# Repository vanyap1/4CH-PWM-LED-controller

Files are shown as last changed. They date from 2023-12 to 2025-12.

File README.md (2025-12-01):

# Потужний 4-канальний контролер освітлення

Контролер призначений для керування чотирма незалежними каналами освітлення за допомогою ШІМ. Підходить для амбіентного підсвічування та роботи з різними сенсорами присутності й освітленості.


## Основні можливості
- Керування **4 незалежними каналами**
- Регулювання яскравості через **ШІМ**
- Інтеграція з зовнішніми сенсорами:
  - Доплерівські сенсори присутності
  - PIR сенсори руху
  - Датчики освітленості
  - Інші сумісні датчики

## Система захисту
- **Температурний контроль** силових транзисторів
- Підтримка **зовнішнього NTC** біля навантаження
- **Захист по струму**
- **Контроль вхідної напруги** з блокуванням роботи в небезпечних діапазонах

## Технічні характеристики
- **Напруга живлення:** 12–26 В  
- **Споживання контролера:** ≤ 50 mA  
- **Максимальний струм комутації:**
  - до **12 А на канал**, або
  - до **12 А сумарно**

## Індикація роботи

### Зелений індикатор
- **Світиться** — нормальна робота  
- **Блимає** — перехідні процеси (зміна режиму, встановлення нового ШІМ)  
- **Вимкнений** — нештатна ситуація

### Червоний індикатор
- **Блимає** — відновлювані критичні стани  
  (критична напруга, перегрів, обмеження по струму, таймер блокування).  
  Виходи **вимкнені**  
- **Світиться** — фатальна помилка  
  (критичний перегрів, неможливість контролювати/відключити навантаження).  
  Скидання після перезапуску, якщо проблема не повторюється

## Програмування сценаріїв
Поведінку контролера, сценарії роботи та інтеграцію з сенсорами можна налаштовувати індивідуально під проєкт.

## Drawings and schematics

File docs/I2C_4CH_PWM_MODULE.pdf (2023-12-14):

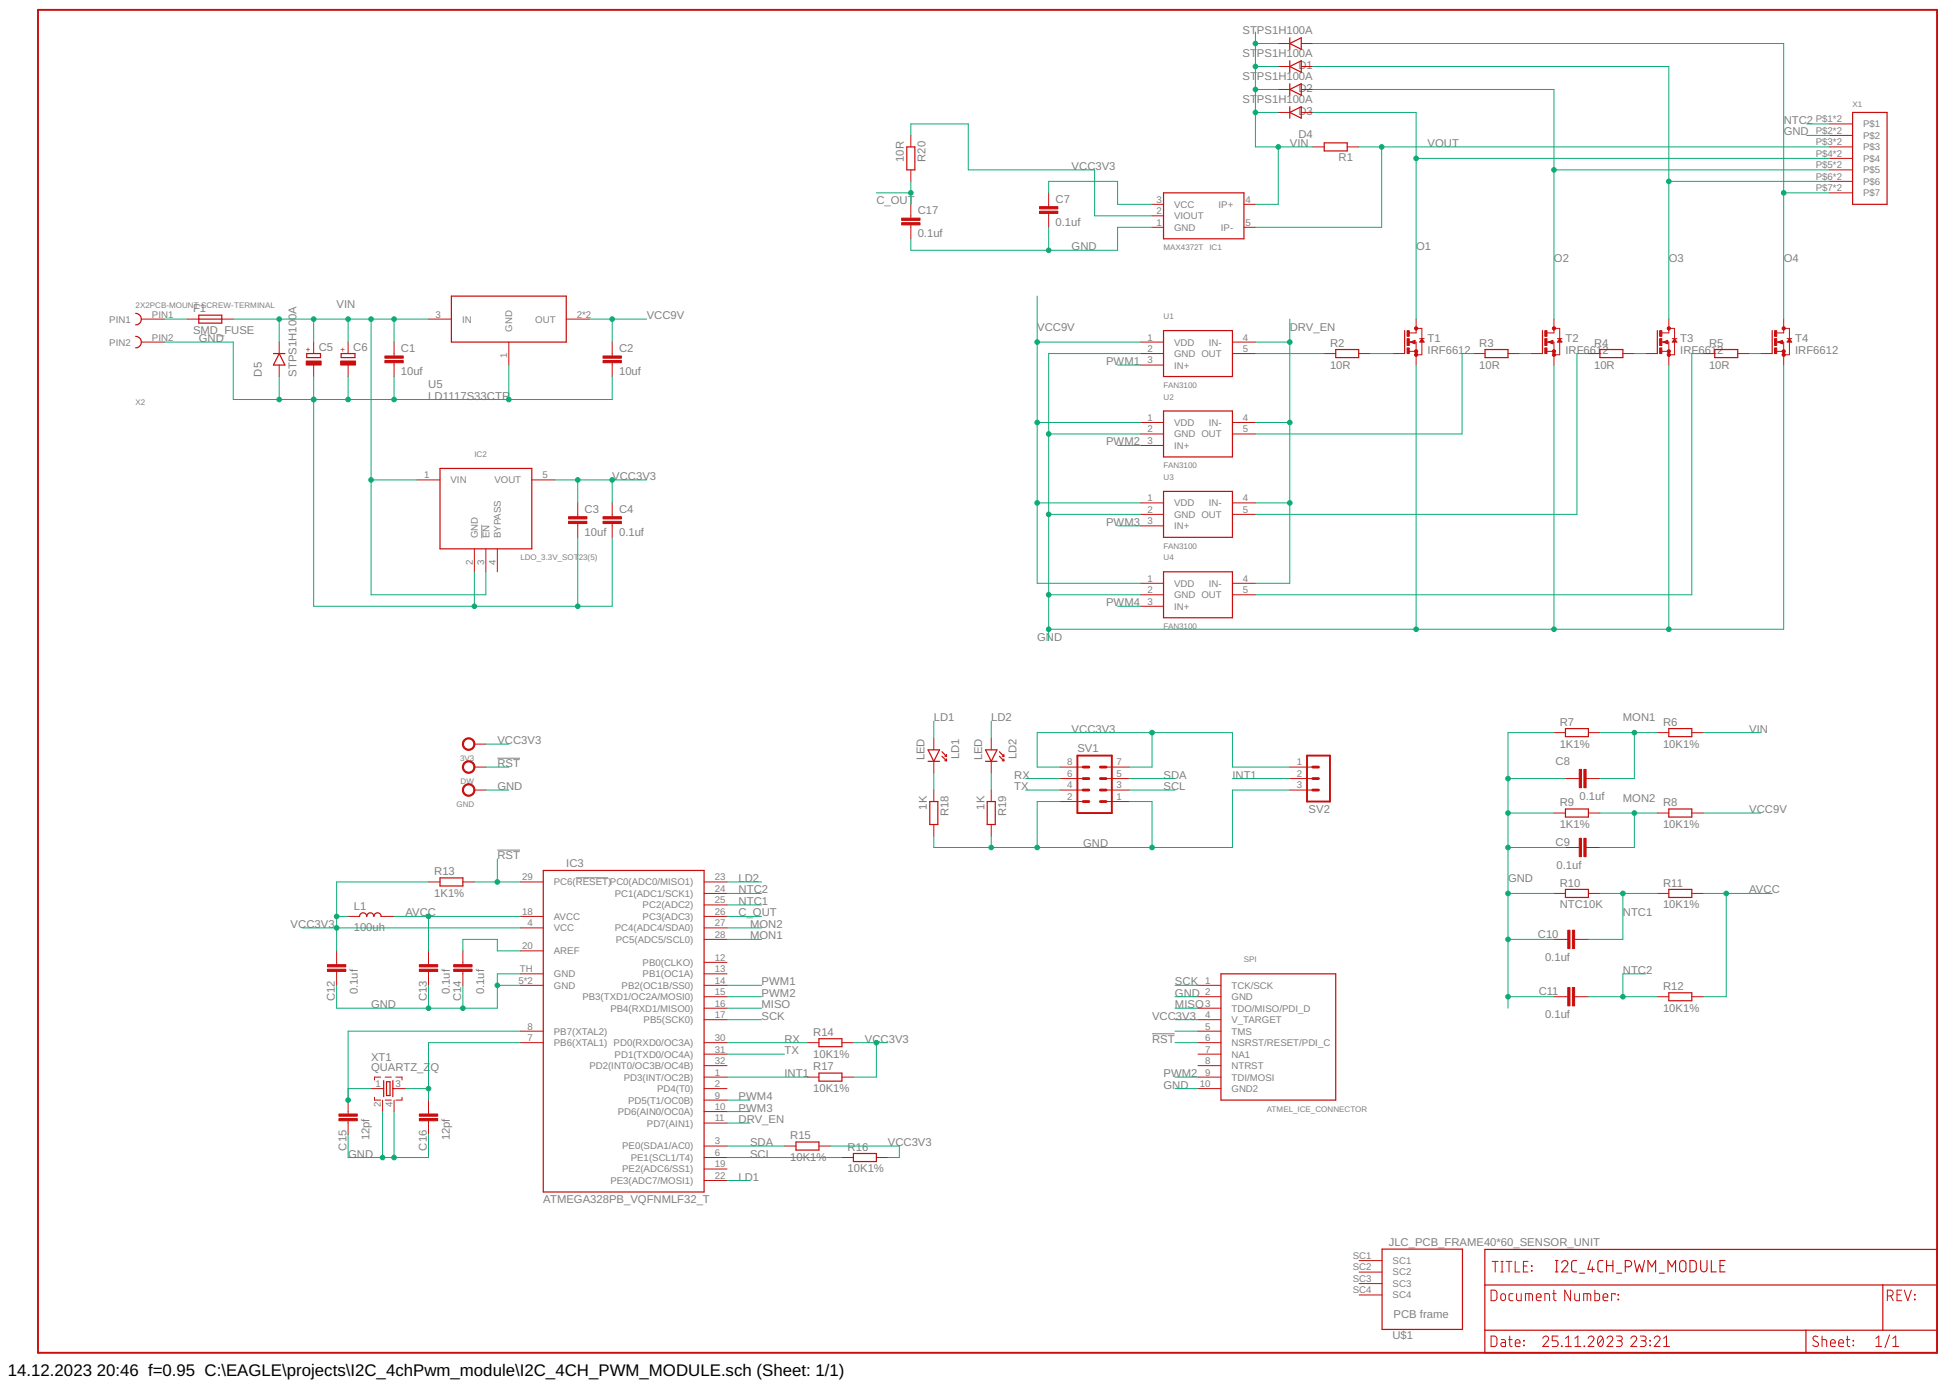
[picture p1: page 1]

14.12.2023 20:46 f=0.95 C:\EAGLE\projects\I2C_4chPwm_module\I2C_4CH_PWM_MODULE.sch (Sheet: 1/1)

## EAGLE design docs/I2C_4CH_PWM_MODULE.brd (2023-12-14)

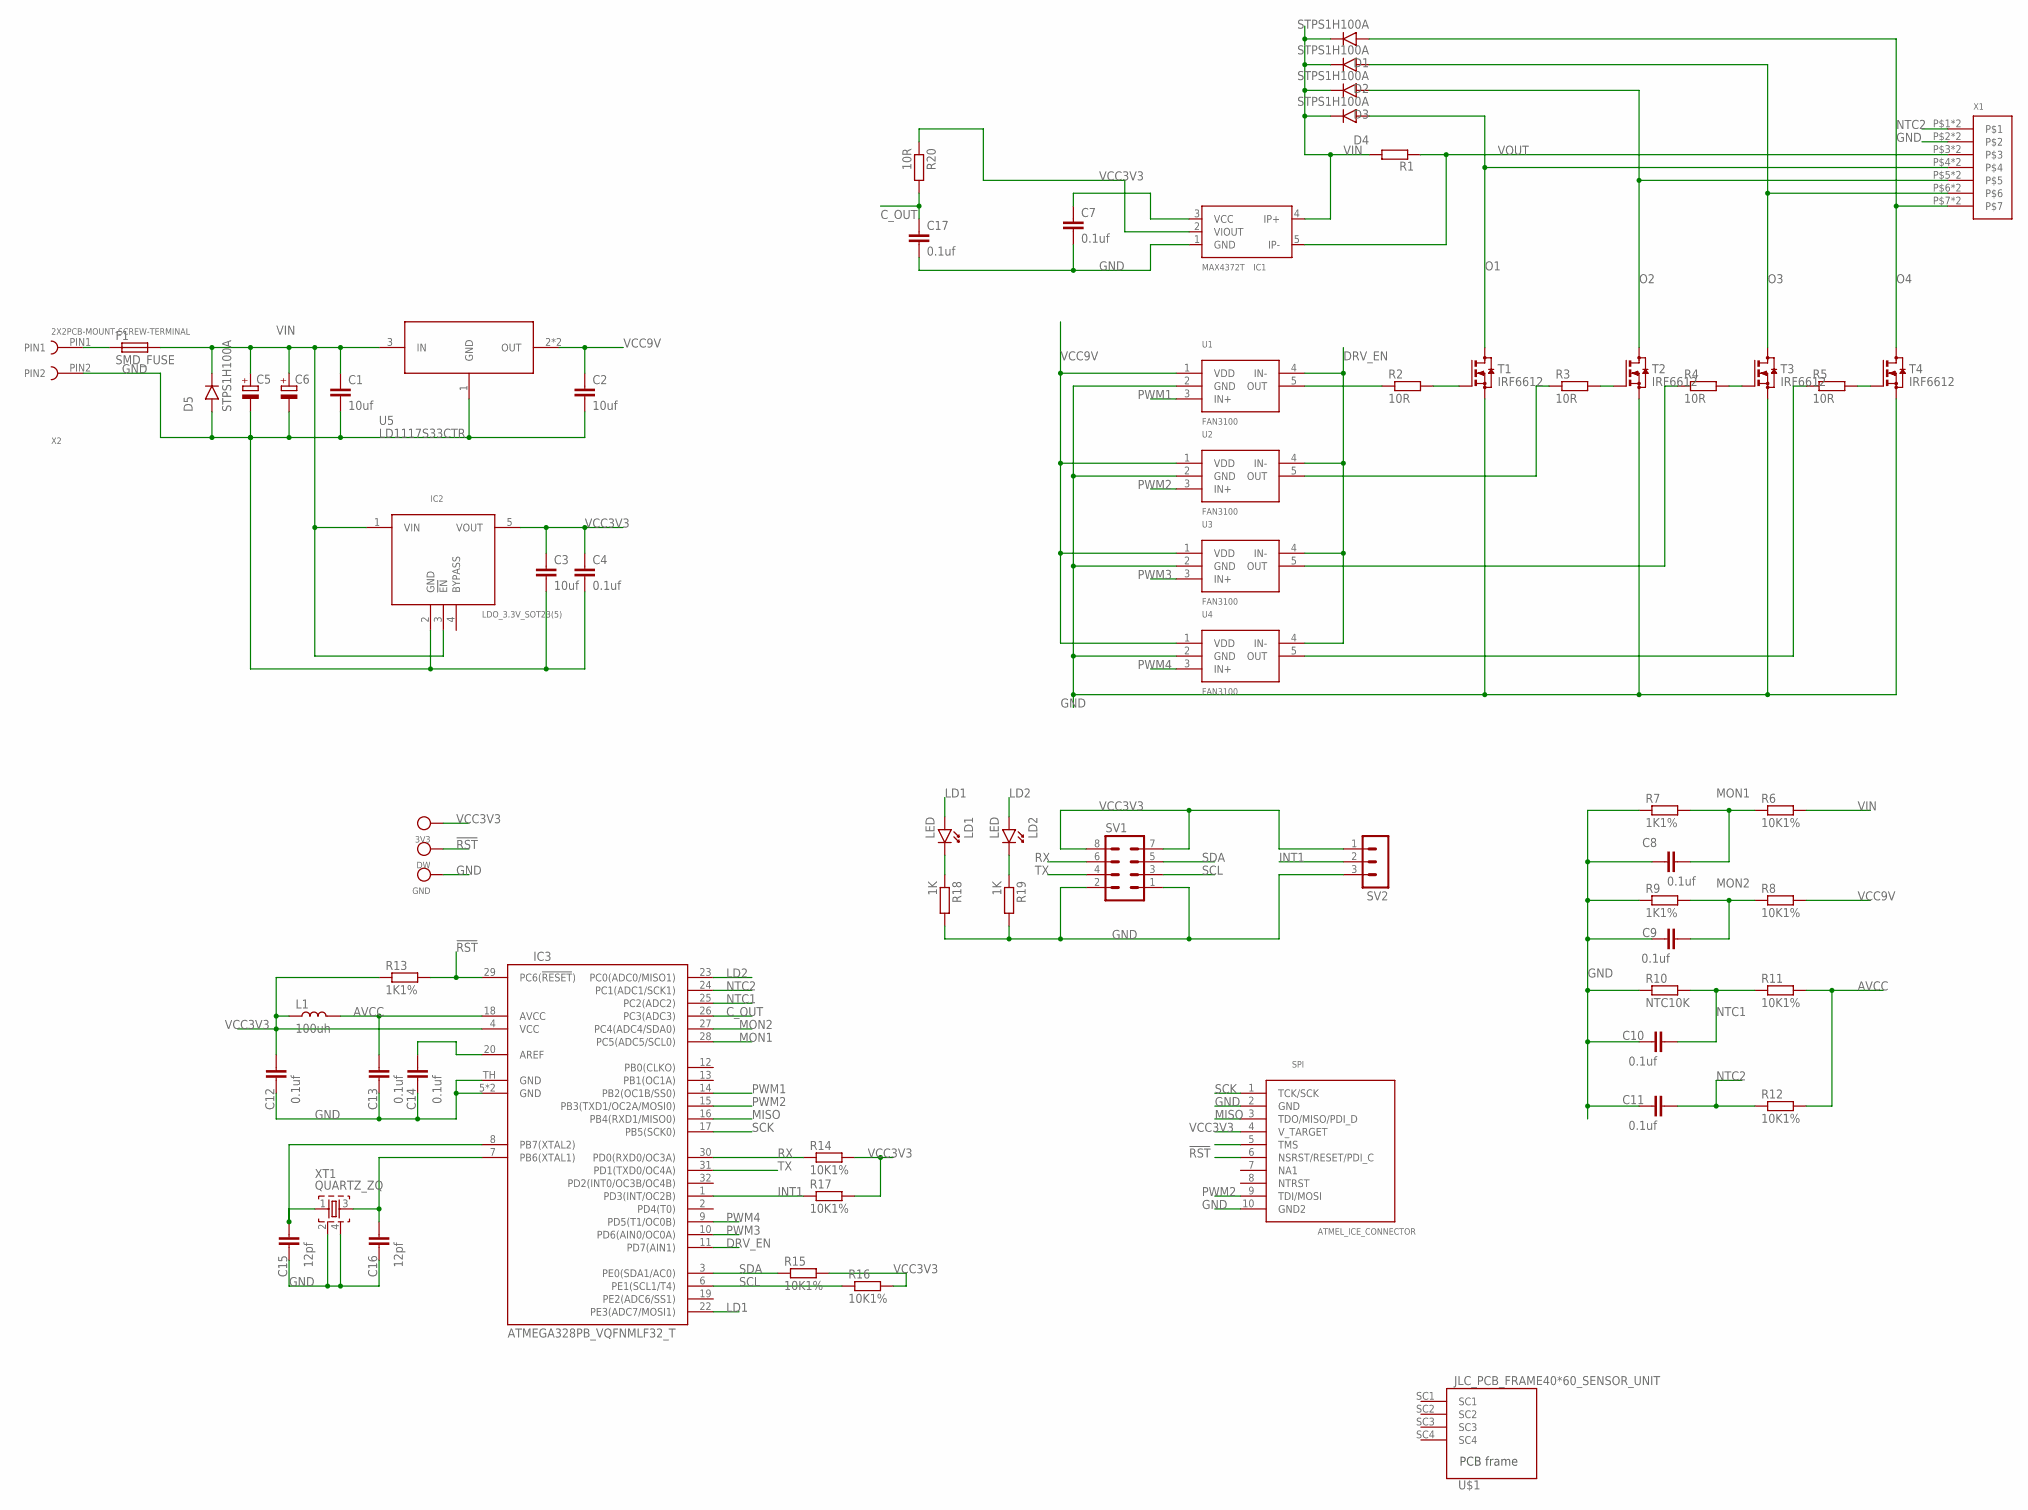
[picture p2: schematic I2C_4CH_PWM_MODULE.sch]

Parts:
3V3: TEST_POINT_D2MM; TP
C1, C2, C3: 10uf; 1206
C4, C7, C8, C9, C10, C11, C12, C13, C14, C17: 0.1uf; 0603
C5, C6: CPOL-EU153CLV-0605; 153CLV-0605
C15, C16: 12pf; 0603
D1, D2, D3, D4, D5: STPS1H100A; SMA403D
DW: TEST_POINT_D2MM; TP
F1: SMD_FUSE; SMD_2410_FUSE_NOK
GND: TEST_POINT_D2MM; TP
IC1: MAX4372T; SOT-23(5)
IC2: LDO_3.3V_SOT23(5); SOT-23(5)
IC3: ATMEGA328PB_VQFNMLF32_T; MLF32-TH
L1: 100uh; 0603
LD1, LD2: LED; 3MM_DIP_LED
R1: SMS-0
R2, R3, R4, R5, R20: 10R; 0603
R6, R8, R11, R12, R14, R15, R16, R17: 10K1%; 0603
R7, R9, R13: 1K1%; 0603
R10: NTC10K; 0603
R18, R19: 1K; 0603
SPI: ATMEL_ICE_CONNECTOR; MINI10P_SPI/JTAG/PDI
SV1: MA04-2
SV2: MA03-1
T1, T2, T3, T4: IRF6612; DIRECTFET_IRF6612
U1, U2, U3, U4: FAN3100; SOT-23(5)
U5: LD1117S33CTR; SOT223
U$1: JLC_PCB_FRAME40*60_SENSOR_UNIT; 40X60_SENSOR_UNIT
X1: WAGO250_X7; WAGO250_FP_7X
X2: 2X2PCB-MOUNT-SCREW-TERMINAL
XT1: QUARTZ_ZQ; QUARTZ_3X3MM

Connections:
!RST: DW.P$1, IC3.29 (PC6(!RESET!)), R13.2, SPI.6 (NSRST/RESET/PDI_C)
AVCC: C13.2, IC3.18 (AVCC), L1.2, R11.2, R12.2
C_OUT: C17.1, IC3.26 (PC3(ADC3)), R20.2
DRV_EN: IC3.11 (PD7(AIN1)), U1.4 (IN-), U2.4 (IN-), U3.4 (IN-), U4.4 (IN-)
GND: C1.2, C2.2, C3.2, C4.2, C5.-, C6.-, C7.2, C8.1, C9.1, C10.1, C11.1, C12.1, C13.1, C14.1, C15.1, C16.1, C17.2, D5.P$2 (A), GND.P$1, IC1.1 (GND), IC2.2 (GND), IC3.5 (GND), IC3.21 (GND), IC3.TH (GND), R7.1, R9.1, R10.1, R18.2, R19.2, SPI.2 (GND), SPI.10 (GND2), SV1.1, SV1.2, SV2.3, T1.S1 (S), T1.S2 (S), T2.S1 (S), T2.S2 (S), T3.S1 (S), T3.S2 (S), T4.S1 (S), T4.S2 (S), U1.2 (GND), U2.2 (GND), U3.2 (GND), U4.2 (GND), U5.1 (GND), X1.P$2, X1.U$2, X2.PIN2, XT1.2, XT1.4
INT1: IC3.1 (PD3(INT/OC2B)), R17.1, SV2.2
LD1: IC3.22 (PE3(ADC7/MOSI1)), LD1.A
LD2: IC3.23 (PC0(ADC0/MISO1)), LD2.A
MISO: IC3.16 (PB4(RXD1/MISO0)), SPI.3 (TDO/MISO/PDI_D)
MON1: C8.2, IC3.28 (PC5(ADC5/SCL0)), R6.1, R7.2
MON2: C9.2, IC3.27 (PC4(ADC4/SDA0)), R8.1, R9.2
unnamed: LD2.K, R19.1
unnamed: F1.P$1 (1), X2.PIN1
unnamed: C15.2, IC3.8 (PB7(XTAL2)), XT1.1
unnamed: C16.2, IC3.7 (PB6(XTAL1)), XT1.3
unnamed: C14.2, IC3.20 (AREF)
unnamed: LD1.K, R18.1
unnamed: IC1.2 (VIOUT), R20.1
unnamed: R2.2, T1.G
unnamed: R2.1, U1.5 (OUT)
unnamed: R3.1, U2.5 (OUT)
unnamed: R3.2, T2.G
unnamed: R4.1, U3.5 (OUT)
unnamed: R4.2, T3.G
unnamed: R5.1, U4.5 (OUT)
unnamed: R5.2, T4.G
NTC1: C10.2, IC3.25 (PC2(ADC2)), R10.2, R11.1
NTC2: C11.2, IC3.24 (PC1(ADC1/SCK1)), R12.1, X1.P$1, X1.U$1
O1: D4.P$2 (A), T1.D1 (D), T1.D2 (D), X1.P$4, X1.U$4
O2: D3.P$2 (A), T2.D1 (D), T2.D2 (D), X1.P$5, X1.U$5
O3: D2.P$2 (A), T3.D1 (D), T3.D2 (D), X1.P$6, X1.U$6
O4: D1.P$2 (A), T4.D1 (D), T4.D2 (D), X1.P$7, X1.U$7
PWM1: IC3.14 (PB2(OC1B/SS0)), U1.3 (IN+)
PWM2: IC3.15 (PB3(TXD1/OC2A/MOSI0)), SPI.9 (TDI/MOSI), U2.3 (IN+)
PWM3: IC3.10 (PD6(AIN0/OC0A)), U3.3 (IN+)
PWM4: IC3.9 (PD5(T1/OC0B)), U4.3 (IN+)
RX: IC3.30 (PD0(RXD0/OC3A)), R14.1, SV1.6
SCK: IC3.17 (PB5(SCK0)), SPI.1 (TCK/SCK)
SCL: IC3.6 (PE1(SCL1/T4)), R16.1, SV1.3
SDA: IC3.3 (PE0(SDA1/AC0)), R15.1, SV1.5
TX: IC3.31 (PD1(TXD0/OC4A)), SV1.4
VCC3V3: 3V3.P$1, C3.1, C4.1, C7.1, C12.2, IC1.3 (VCC), IC2.5 (VOUT), IC3.4 (VCC), L1.1, R13.1, R14.2, R15.2, R16.2, R17.2, SPI.4 (V_TARGET), SV1.7, SV1.8, SV2.1
VCC9V: C2.1, R8.2, U1.1 (VDD), U2.1 (VDD), U3.1 (VDD), U4.1 (VDD), U5.2 (OUT), U5.4 (OUT)
VIN: C1.1, C5.+, C6.+, D1.P$1 (C), D2.P$1 (C), D3.P$1 (C), D4.P$1 (C), D5.P$1 (C), F1.P$2 (2), IC1.4 (IP+), IC2.1 (VIN), IC2.3 (!EN!), R1.1, R6.2, U5.3 (IN)
VOUT: IC1.5 (IP-), R1.2, X1.P$3, X1.U$3

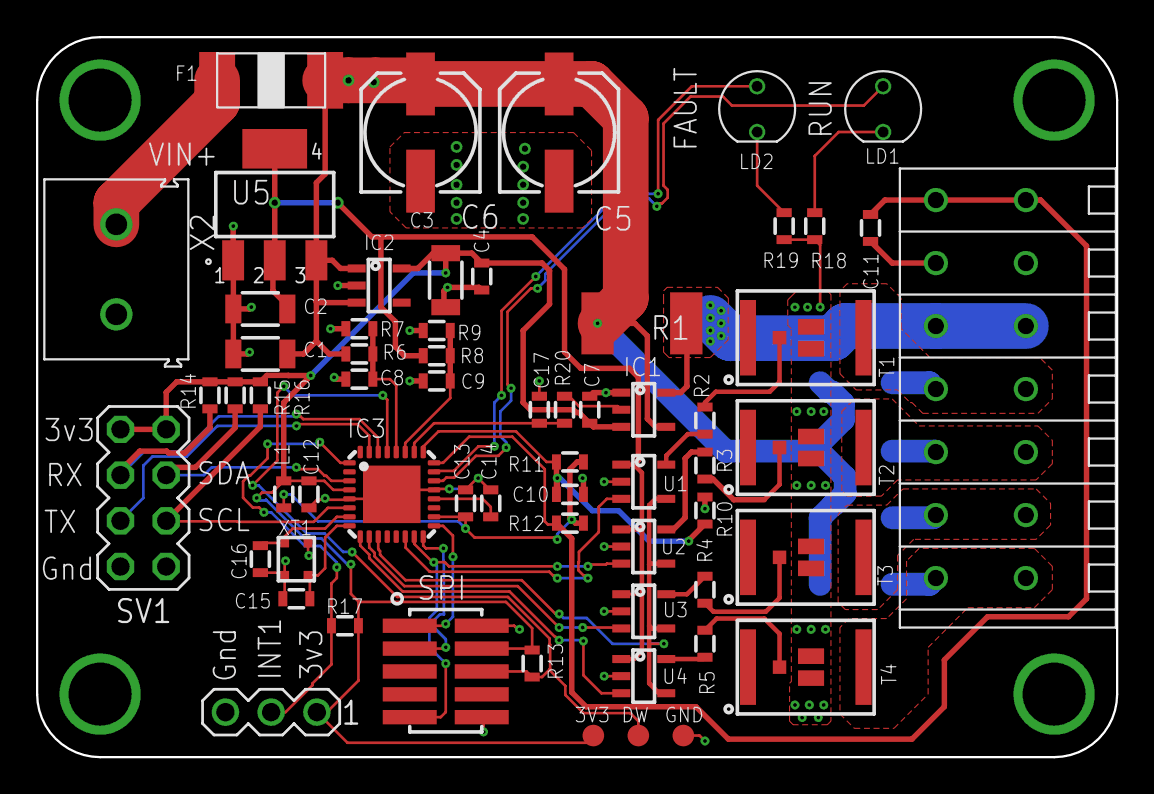
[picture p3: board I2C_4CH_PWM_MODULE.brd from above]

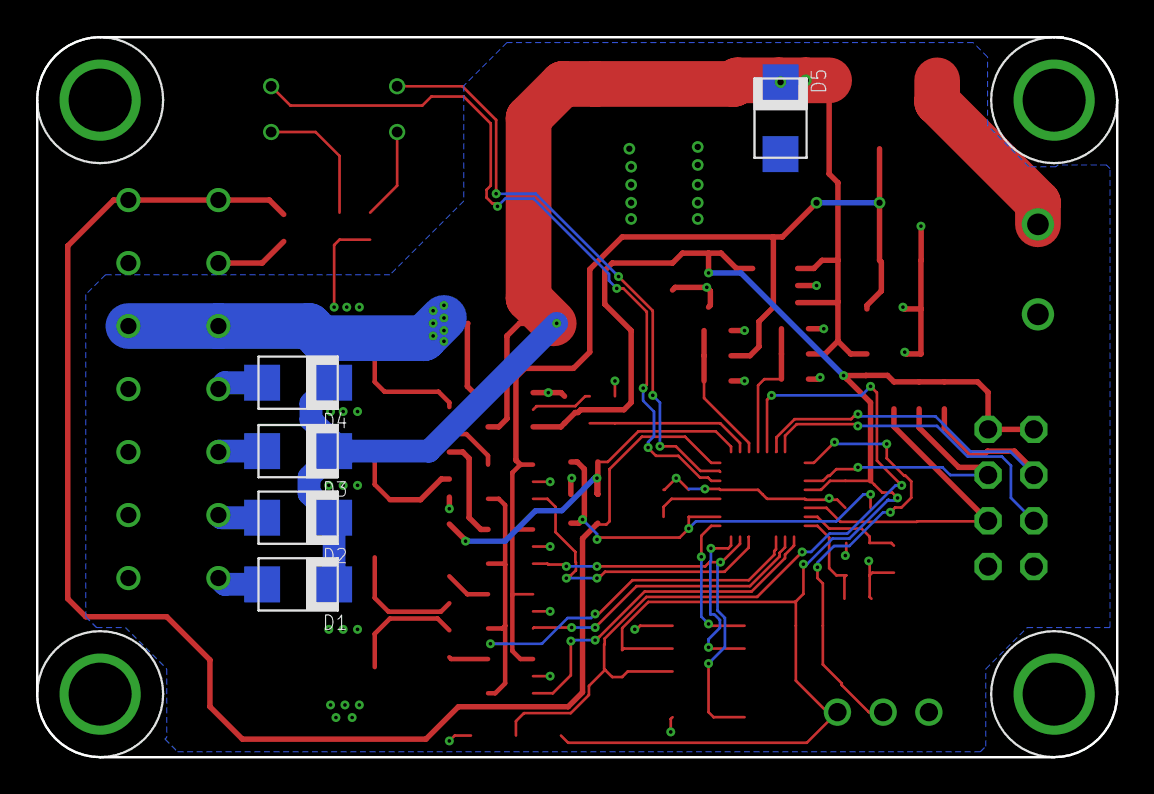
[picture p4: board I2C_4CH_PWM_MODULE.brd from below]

Board: 2 copper layers, 60.0 x 40.0 mm, 68 parts (6 on the bottom side), 45 nets.

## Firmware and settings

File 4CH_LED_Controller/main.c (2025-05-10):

/*
 * 4CH_LED_Controller.c
 *
 * Created: 14.12.2023 18:12:35
 * Author : Vanya
 */ 

#include "config.h"
#include <avr/io.h>
#include <util/delay.h>
#include <avr/interrupt.h>
#include <avr/sleep.h>
#include <avr/wdt.h>

#include "string.h"
#include "stdbool.h"
#include "uart_hal.h"
#include "gpio_driver.h"
#include "twi_hal1.h"
#include "adc_hal.h"
#include "spi1_hall.h"
#include "stdint.h"

#include <stdio.h>
static FILE mystdout = FDEV_SETUP_STREAM((void *)uart_send_byte, NULL, _FDEV_SETUP_WRITE);

gpio drvEn = {(uint8_t *)&PORTD , PORTD7};
gpio ledRun = {(uint8_t *)&PORTE , PORTE3};
gpio ledFail = {(uint8_t *)&PORTC , PORTC0};

gpio sData = {(uint8_t *)&PORTE , PORTE0};
gpio sClock = {(uint8_t *)&PORTE , PORTE1};



gpio ch1Config = {(uint8_t *)&PORTB , PORTB2};
gpio ch2Config = {(uint8_t *)&PORTB , PORTB3};
gpio ch3Config = {(uint8_t *)&PORTD , PORTD6};
gpio ch4Config = {(uint8_t *)&PORTD , PORTD5};

#define	CH1					OCR1B 	
#define CH2					OCR2A
#define CH3					OCR0A		
#define CH4					OCR0B

#define VOLTMONITOR1		4	//input voltage channel
#define VOLTMONITOR2		5	//FET driver voltage
#define CURRMONITOR			3	//output current
#define NTC1				2	//onboard ntc
#define NTC2				1	//external ntc

#define CRITICALVOLTAGE		10500
#define WORKRESTOREVOLTAGE	11000
#define LIGHTTARGETLEVEL	255
#define INCRSTEPTIME		20

#define TWIADDR				0x54
#define TWISPEED			400000
uint8_t twiDataBuff[64];
uint8_t	pwmChCalcReg[4];

uint8_t TAB_PWM_1[256] = { 0 , 0 , 0 , 0 , 0 , 0 , 0 , 0 , 0 , 0 , 0 , 1 , 1 , 1 , 1 , 1,
	1 , 2 , 2 , 2 , 2 , 3 , 3 , 3 , 3 , 4 , 4 , 4 , 5 , 5 , 5 , 6,
	6 , 6 , 7 , 7 , 7 , 8 , 8 , 9 , 9 , 9 , 10 , 10 , 11 , 11 , 12 , 12,
	13 , 13 , 13 , 14 , 14 , 15 , 16 , 16 , 17 , 17 , 18 , 18 , 19 , 19 , 20 , 21,
	21 , 22 , 22 , 23 , 24 , 24 , 25 , 25 , 26 , 27 , 27 , 28 , 29 , 30 , 30 , 31,
	32 , 32 , 33 , 34 , 35 , 35 , 36 , 37 , 38 , 38 , 39 , 40 , 41 , 42 , 42 , 43,
	44 , 45 , 46 , 46 , 47 , 48 , 49 , 50 , 51 , 52 , 53 , 53 , 54 , 55 , 56 , 57,
	58 , 59 , 60 , 61 , 62 , 63 , 64 , 65 , 66 , 67 , 68 , 69 , 70 , 71 , 72 , 73,
	74 , 75 , 76 , 77 , 78 , 79 , 80 , 81 , 82 , 83 , 84 , 86 , 87 , 88 , 89 , 90,
	91 , 92 , 93 , 95 , 96 , 97 , 98 , 99 , 100 , 102 , 103 , 104 , 105 , 106 , 108 , 109,
	110 , 111 , 113 , 114 , 115 , 116 , 118 , 119 , 120 , 122 , 123 , 124 , 125 , 127 , 128 , 129,
	131 , 132 , 133 , 135 , 136 , 137 , 139 , 140 , 142 , 143 , 144 , 146 , 147 , 149 , 150 , 151,
	153 , 154 , 156 , 157 , 159 , 160 , 162 , 163 , 164 , 166 , 167 , 169 , 170 , 172 , 173 , 175,
	176 , 178 , 180 , 181 , 183 , 184 , 186 , 187 , 189 , 190 , 192 , 194 , 195 , 197 , 198 , 200,
	202 , 203 , 205 , 207 , 208 , 210 , 211 , 213 , 215 , 216 , 218 , 220 , 221 , 223 , 225 , 227,
228 , 230 , 232 , 233 , 235 , 237 , 239 , 240 , 242 , 244 , 246 , 247 , 249 , 251 , 253 , 255 };


uint16_t inputVoltage = 0;
uint16_t fetVoltage = 0;
uint16_t outputCurrent = 0;
int16_t ntc1Celsius = 0;
int16_t ntc2Celsius = 0;
uint8_t	lightLevel = 0;
uint8_t protectionFlg = 0;
	
	
	
int main(void)
{
	sei();
	wdt_enable(WDTO_2S);
	//uart_init(250000, 1);
	//twi1_init(400000);
	twi1_slave_init(TWIADDR, &twiDataBuff, TWISPEED);
	
	gpio_set_pin_direction(&sData , PORT_DIR_IN);
	gpio_set_pin_direction(&sClock , PORT_DIR_IN);
	gpio_set_pin_direction(&drvEn , PORT_DIR_OUT); gpio_set_pin_level(&drvEn, true);
	gpio_set_pin_direction(&ledRun , PORT_DIR_OUT); gpio_set_pin_level(&ledRun, false);
	gpio_set_pin_direction(&ledFail , PORT_DIR_OUT); gpio_set_pin_level(&ledFail, true);
	
	gpio_set_pin_direction(&ch1Config , PORT_DIR_OUT); gpio_set_pin_level(&ch1Config, false);
	gpio_set_pin_direction(&ch2Config , PORT_DIR_OUT); gpio_set_pin_level(&ch2Config, false);
	gpio_set_pin_direction(&ch3Config , PORT_DIR_OUT); gpio_set_pin_level(&ch3Config, false);
	gpio_set_pin_direction(&ch4Config , PORT_DIR_OUT); gpio_set_pin_level(&ch4Config, false);
    
	sei();
	
	adc_init();
	
	//Set channels default values
	CH1 = 0;
	CH2 = 0;
	CH3 = 0;
	CH4 = 0;

	//Setup timer 0, CH A and B for out 3 and 4
	TCCR0A = (0b10 << COM0A0) | (0b10 << COM0B0) | (0b01 << WGM00);
	TCCR0B = (0b0 << WGM02) | (0b1 << CS10);
	
	//Setup timer 1, CH B for out 1
	TCCR1A = (0b10 << COM1B0) | (0b01 << WGM00);
	TCCR1B = (0b0 << WGM02) | (0b1 << CS10);
	
	//Setup timer 2, CH A for out 2
	TCCR2A = (0b10 << COM2A0) | (0b01 << WGM00);
	TCCR2B = (0b0 << WGM02) | (0b1 << CS10);
	
	
	_delay_ms(100);
	gpio_set_pin_level(&ledFail, false);
    while (1) 
    {
		wdt_reset();
		ntc1Celsius = getNTC(NTC1);
		inputVoltage = get_mVolt(VOLTMONITOR1);
		outputCurrent = get_mAmps(CURRMONITOR);
		
		
		if (inputVoltage <= CRITICALVOLTAGE){
			protectionFlg = 1;
		}
		if (inputVoltage >= WORKRESTOREVOLTAGE){
			protectionFlg = 0;
		}
		
		if(protectionFlg != 0){
			gpio_set_pin_level(&drvEn, true);
			gpio_set_pin_level(&ledRun, false);
			gpio_toggle_pin_level(&ledFail);
			
			
			lightLevel=0;
			_delay_ms(250);
		}else{
			gpio_set_pin_level(&drvEn, false);
			gpio_set_pin_level(&ledFail, false);
			gpio_set_pin_level(&ledRun, true);
			
			if(lightLevel < LIGHTTARGETLEVEL){
				lightLevel++;
				_delay_ms(INCRSTEPTIME);
			}
			
			
			for (uint8_t ch = 0; ch<=sizeof(pwmChCalcReg); ch++)
			{
				if(pwmChCalcReg[ch] < twiDataBuff[ch]){
					if(pwmChCalcReg[ch]!= 255){
						pwmChCalcReg[ch]++;
					}
				}
				else{
					if(pwmChCalcReg[ch]!= 0){
						pwmChCalcReg[ch]--;
					}
				}
			}
			CH1 = TAB_PWM_1[pwmChCalcReg[0]];
			CH2 = TAB_PWM_1[pwmChCalcReg[1]];
			CH3 = TAB_PWM_1[pwmChCalcReg[2]];
			CH4 = TAB_PWM_1[pwmChCalcReg[3]];
			_delay_ms(1);
			
		}
		
		
		
		
		
		
		
		
		
		
		
    }
}
